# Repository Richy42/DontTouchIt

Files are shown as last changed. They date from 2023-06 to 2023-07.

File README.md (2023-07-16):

# DontTouchIt
Is an inductive distance sensor board based on the TI LDC1614 chip.

It is intended for 3d Printers to measure the distance to the printing bed.
It speeds up quad gantry levelling and bed mesh calibration as no z movement is needed to get the distance between the probe and the bed.

As it supports three sensors it could probably be used also for homing.

## The board



### Coils cut away and one mounted on an angle


### 3d Printed case in the size similar to an Omron (like) probe




### Mounted on an Voron 2.4


## Klipper 3D support
I added experimental support to klipper and the following video shows a Quad Gantry Level run
https://youtu.be/B2gruTA73uU

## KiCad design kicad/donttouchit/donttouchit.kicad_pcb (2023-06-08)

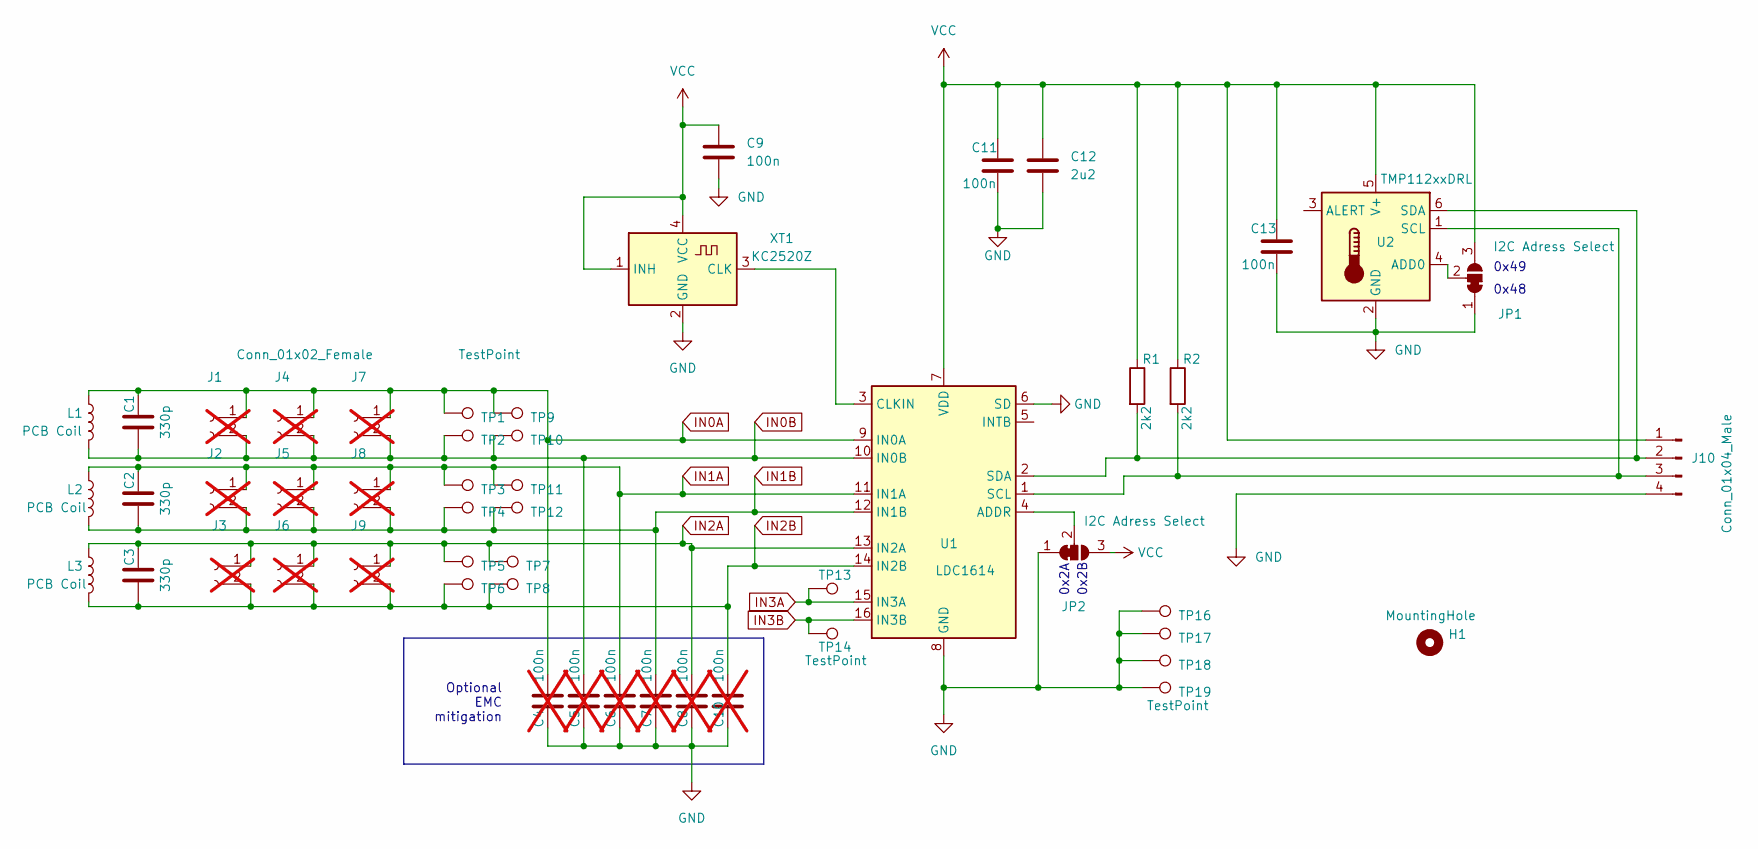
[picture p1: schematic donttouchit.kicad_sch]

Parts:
C1, C2, C3: 330p; C_0603_1608Metric_Pad1.08x0.95mm_HandSolder
C4, C5, C6, C7, C8, C10: 100n; C_0603_1608Metric_Pad1.08x0.95mm_HandSolder; not fitted
C9, C11, C13: 100n; C_0603_1608Metric_Pad1.08x0.95mm_HandSolder
C12: 2u2; C_0603_1608Metric_Pad1.08x0.95mm_HandSolder
H1: MountingHole; MountingHole_3.2mm_M3
J1, J2, J3, J4, J5, J6: Conn_01x02_Female; PCBConnPads; not fitted
J7, J8, J9: Conn_01x02_Female; PCBConnPadsLong; not fitted
J10: Conn_01x04_Male; JST_PH_B4B-PH-SM4-TB_1x04-1MP_P2.00mm_Vertical
JP1, JP2: I2C Adress Select; SolderJumper-3_P1.3mm_Bridged12_RoundedPad1.0x1.5mm
L1, L2, L3: PCB Coil; Coil
R1, R2: 2k2; R_0603_1608Metric_Pad0.98x0.95mm_HandSolder
TP1, TP2, TP3, TP4, TP5, TP6, TP7, TP8, TP9, TP10, TP11, TP12, TP13, TP14, TP16, TP17, TP18, TP19: TestPoint; TestPoint_THTPad_1.5x1.5mm_Drill0.7mm
U1: LDC1614; WQFN-16-1EP_4x4mm_P0.5mm_EP2.6x2.6mm_ThermalVias
U2: TMP112xxDRL; SOT-563
XT1: KC2520Z; Oscillator_SMD_Kyocera_KC2520Z-4Pin_2.5x2.0mm

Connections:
GND: C4.2, C5.2, C6.2, C7.2, C8.2, C9.2, C10.2, C11.2, C12.2, C13.2, J10.4, JP1.1 (A), JP2.1 (A), TP16.1, TP17.1, TP18.1, TP19.1, U1.6 (SD), U1.8 (GND), U1.17 (GND), U2.2 (GND), XT1.2 (GND)
IN0A: C1.2, C4.1, J1.1, J4.1, J7.1, L1.1, TP1.1, TP9.1, U1.9 (IN0A)
IN0B: C1.1, C5.1, J1.2, J4.2, J7.2, L1.2, TP2.1, TP10.1, U1.10 (IN0B)
IN1A: C2.2, C6.1, J2.1, J5.1, J8.1, L2.1, TP3.1, TP11.1, U1.11 (IN1A)
IN1B: C2.1, C7.1, J2.2, J5.2, J8.2, L2.2, TP4.1, TP12.1, U1.12 (IN1B)
IN2A: C3.2, C8.1, J3.1, J6.1, J9.1, L3.1, TP5.1, TP7.1, U1.13 (IN2A)
IN2B: C3.1, C10.1, J3.2, J6.2, J9.2, L3.2, TP6.1, TP8.1, U1.14 (IN2B)
IN3A: TP13.1, U1.15 (IN3A)
IN3B: TP14.1, U1.16 (IN3B)
unnamed: J10.2, R1.2, U1.2 (SDA), U2.6 (SDA)
unnamed: J10.3, R2.2, U1.1 (SCL), U2.1 (SCL)
unnamed: JP1.2 (C), U2.4 (ADD0)
unnamed: JP2.2 (C), U1.4 (ADDR)
unnamed: U1.3 (CLKIN), XT1.3 (CLK)
VCC: C9.1, C11.1, C12.1, C13.1, J10.1, JP1.3 (B), JP2.3 (B), R1.1, R2.1, U1.7 (VDD), U2.5 (V+), XT1.1 (INH), XT1.4 (VCC)

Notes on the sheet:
0x48
0x2B
Optional EMC mitigation
0x2A
0x49

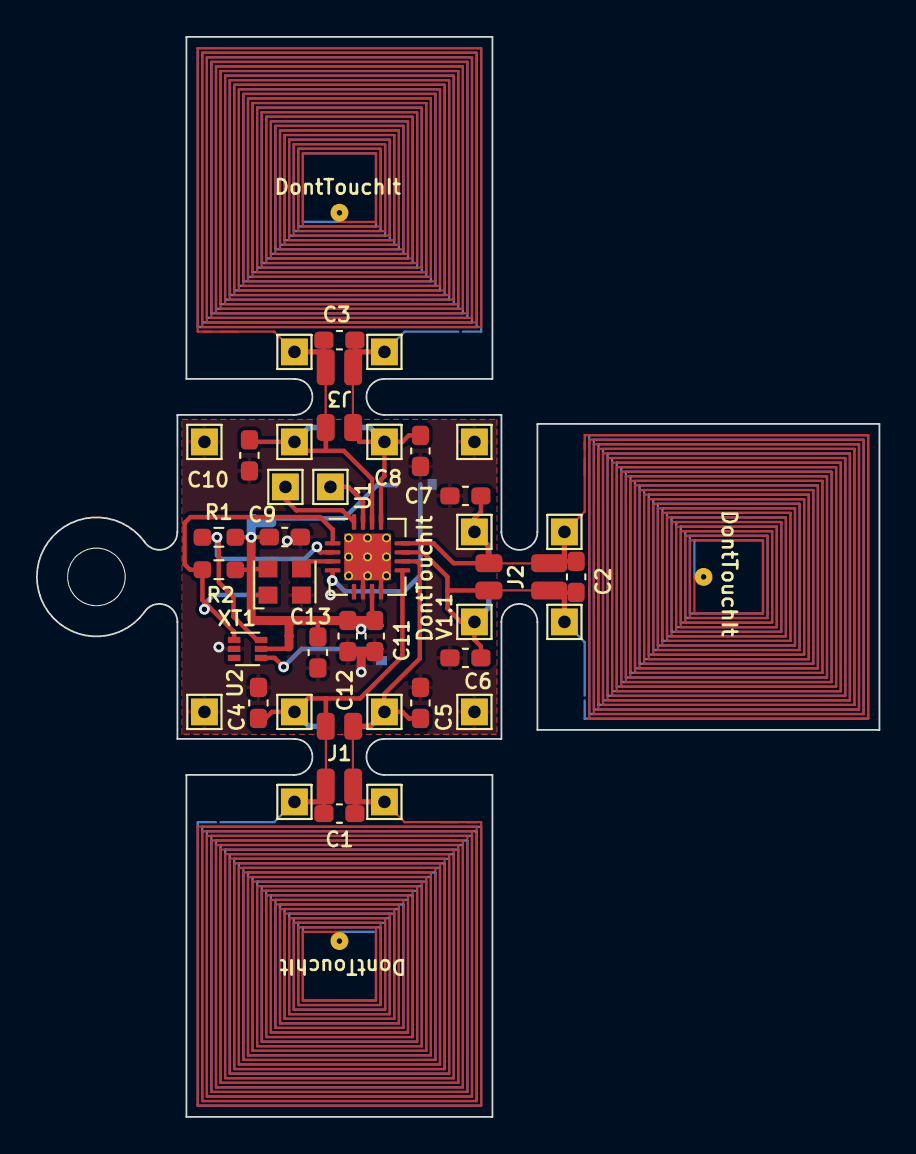
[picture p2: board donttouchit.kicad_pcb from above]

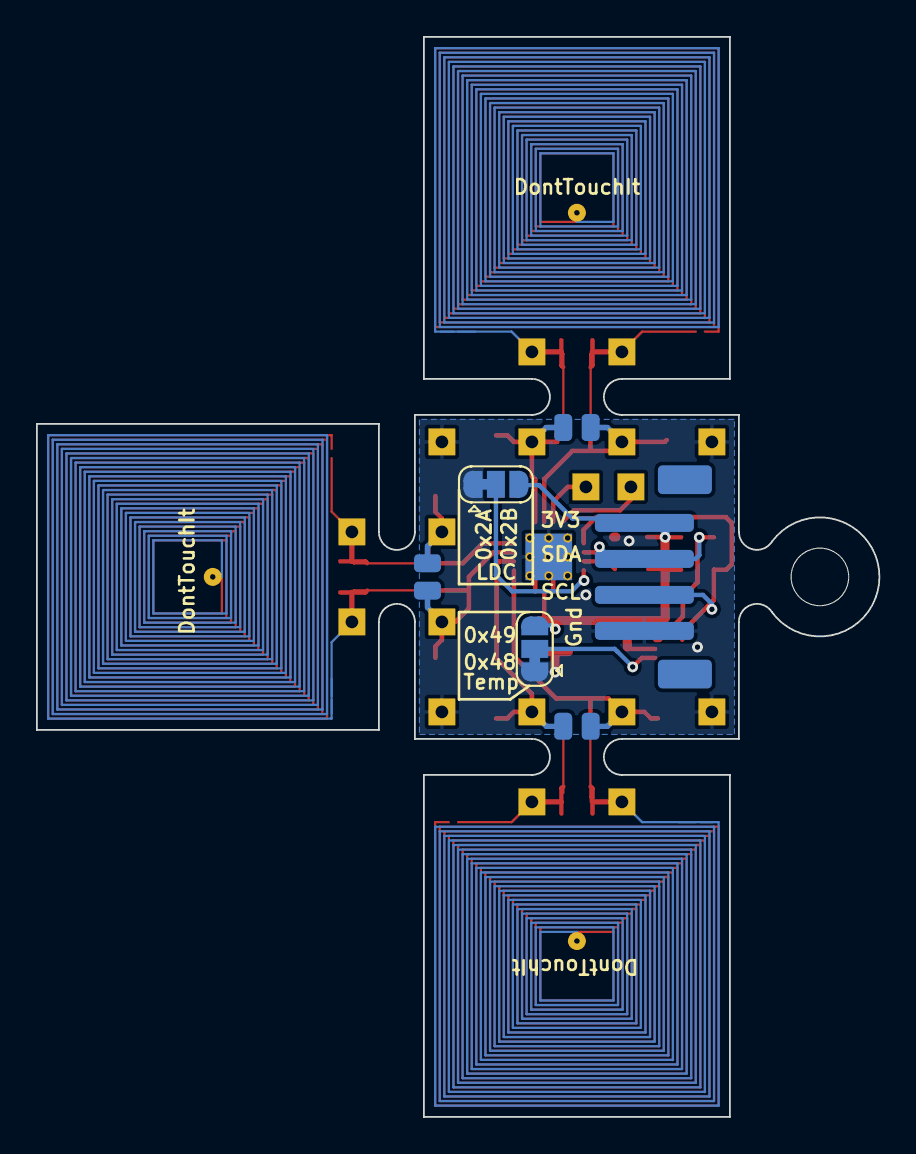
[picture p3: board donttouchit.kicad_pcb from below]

Board: 2 copper layers, 46.8 x 60.0 mm, 52 parts (9 on the bottom side), 15 nets.

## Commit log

2023-05-26 i2c pull up resistors added
    [donttouchit.kicad_pcb, donttouchit.kicad_sch]
2023-05-26 temperature sensor added
    [donttouchit.kicad_pcb, donttouchit.kicad_sch]
2023-06-08 I2C address solderbridges added / mounting hole added / size reduced for control section
    [donttouchit.kicad_pcb, donttouchit.kicad_sch]
2023-06-17 ESD capacitor values corrected / Tempsensor name updated
    [donttouchit.kicad_sch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]
2023-06-17 V1.1 fabrication files generated
    [donttouchit-B_Cu.gbr, donttouchit-B_Mask.gbr, donttouchit-B_Paste.gbr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]
